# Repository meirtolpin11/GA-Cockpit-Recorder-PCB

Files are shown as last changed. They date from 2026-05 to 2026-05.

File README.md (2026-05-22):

# GA Cockpit Recorder — TRS+TRRS Adapter

Adapter, top view

A small adapter PCB and 3D-printed enclosure for recording audio from a
general aviation (GA) cockpit intercom onto a phone, dictaphone, action
camera, or other consumer recorder.

The board breaks out a GA intercom feed into both **3.5 mm TRS** and
**3.5 mm TRRS** jacks so it can be connected to almost any recording device:

- **TRS** — line-style stereo output (standard recorders, line-in inputs).
- **TRRS** — phone-style 4-conductor output (smartphones, headsets that
  expect a mic on the ring/sleeve).

## Important: this is only the adapter

This board does **not** plug directly into the aircraft. To use it you also
need:

1. **A PL splitter** for the cockpit GA jacks (the dual PJ-055 / PJ-068
   "PL" connectors used in GA aircraft). The splitter taps the intercom
   audio without disconnecting the pilot's headset.
2. **A PL-to-TRS cable or adapter** that connects the splitter to this
   adapter board's input jack.

Signal chain:

```
Cockpit GA jacks ── PL splitter ── PL-to-TRS cable ── [this adapter] ── phone / recorder
```

Example of the PL-to-TRS cable that feeds the adapter:

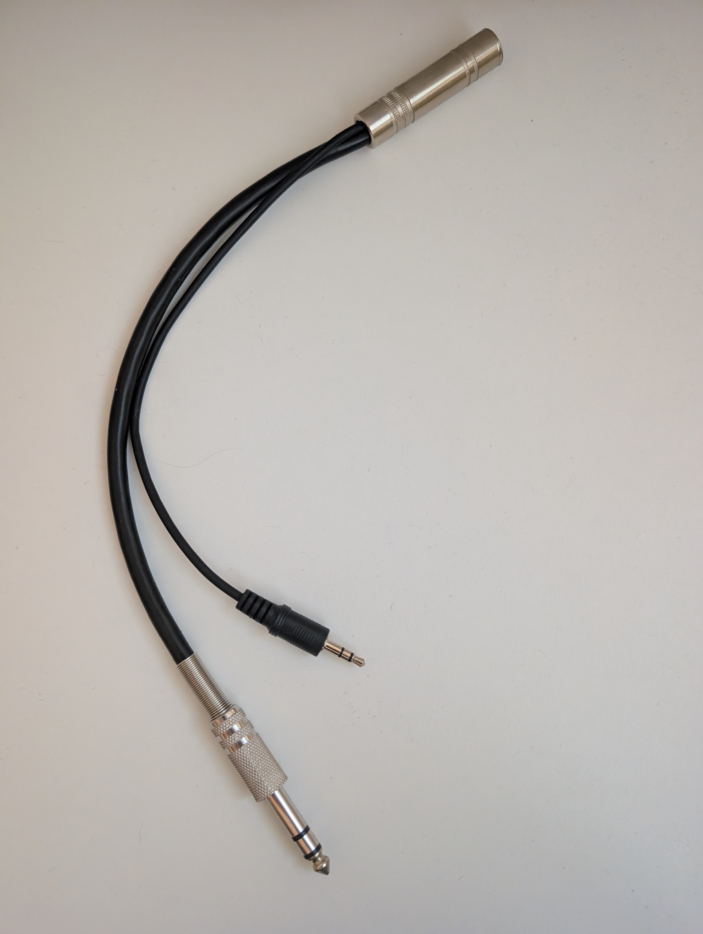
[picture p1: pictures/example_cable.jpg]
Example PL-to-TRS cable


## Connections

| Side | Photo | Description |
|---|---|---|
| Input  | Input | TRS jack — connect the PL-to-TRS cable from the PL splitter here. |
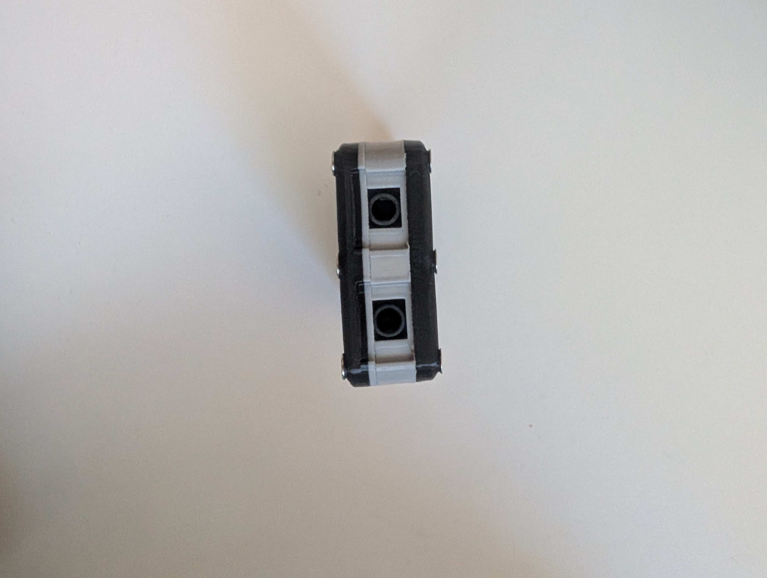
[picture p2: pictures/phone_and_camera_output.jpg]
Output
| Output |  | TRS + TRRS jacks — connect a phone, action camera, or recorder. |

## Schematic

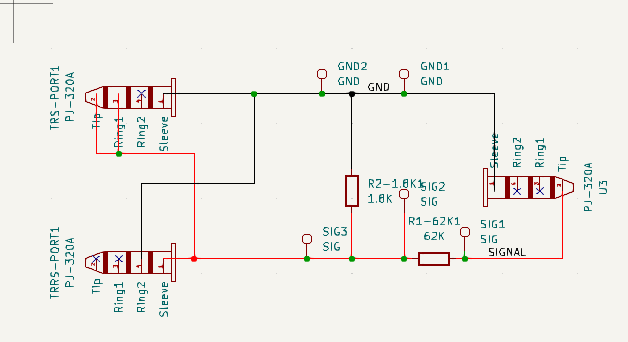
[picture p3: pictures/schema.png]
Schematic


The full editable KiCad schematic is in
[`pcb/Recorder-TRS+TRRS.kicad_sch`](pcb/Recorder-TRS+TRRS.kicad_sch).

## Repository layout

```
pcb/                          KiCad 9 project
  Recorder-TRS+TRRS.kicad_pro     project file
  Recorder-TRS+TRRS.kicad_sch     schematic
  Recorder-TRS+TRRS.kicad_pcb     PCB layout
  PJ-320A.kicad_sym               vendored symbol (upstream ships only legacy .lib)
  PJ-320A_KiCad_Library/          git submodule -> nathanhborger/PJ-320A_KiCad_Library
  sym-lib-table / fp-lib-table    project-local library tables (KIPRJMOD-relative)

case/                         3D-printable enclosure
  top.stl / middle.stl / bottom.stl
  case.3mf                    source file with all parts

pictures/                     photos of the assembled board and case
```

## Opening the KiCad project

The footprint library is a git submodule, so clone with submodules:

```sh
git clone --recurse-submodules git@github.com:meirtolpin11/GA-Cockpit-Recorder-PCB.git
```

If you already cloned without `--recurse-submodules`:

```sh
git submodule update --init
```

Then open `pcb/Recorder-TRS+TRRS.kicad_pro` in KiCad 9.

The project ships its own `sym-lib-table` and `fp-lib-table` using
`${KIPRJMOD}`-relative paths, so no global KiCad library registration is
needed. If you already have a `PJ-320A` / `PJ-320A_Library` entry in your
global tables you may see a duplicate-nickname warning — the project-local
entry is the one that resolves correctly for this project.

## Ordering the PCB

The board has been successfully manufactured by [JLCPCB](https://jlcpcb.com/)
and that is the recommended way to get one made — it's inexpensive, the
turnaround is fast, and the default 1.6 mm FR-4 stack-up works well for
this design.

Gerbers are not committed to the repo (the KiCad design is the source of
truth). To produce manufacturing files yourself:

1. Open `pcb/Recorder-TRS+TRRS.kicad_pcb` in KiCad.
2. **File → Fabrication Outputs → Gerbers** — use the JLCPCB preset or
   the KiCad defaults.
3. **File → Fabrication Outputs → Drill Files** — Excellon, PTH + NPTH.
4. Zip the resulting folder and upload it to
   [jlcpcb.com](https://jlcpcb.com/) (or another fab of your choice).

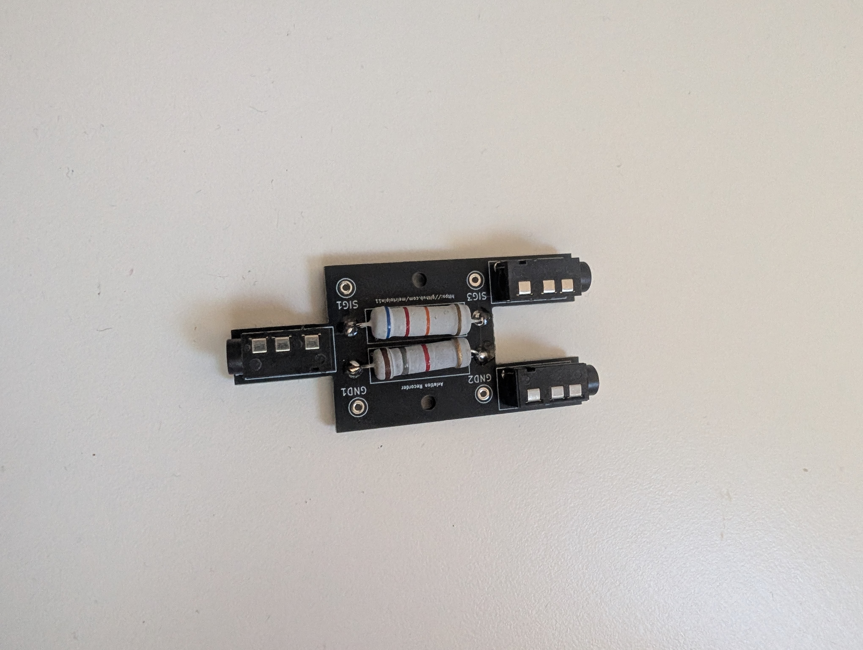
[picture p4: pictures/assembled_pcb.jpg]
Assembled PCB


## Printing the case

The case prints in three parts (`top.stl`, `middle.stl`, `bottom.stl`).
`case.3mf` is the source file containing all parts together — open it in
your slicer if you'd like to print the set in one job.

<p>
  Case, side view
  Case, bottom view
</p>

## Credits

This design is based on the wiring scheme described in this
[Rivet Bangers forum thread](https://www.rivetbangers.com/forums/viewtopic.php?t=4753).

Special thanks to forum user **bullojm1** for sharing the original idea and
schematic — without that write-up this adapter would not exist. Thank you!

## License

This project is licensed under the **Creative Commons
Attribution-NonCommercial-ShareAlike 4.0 International License**
([CC BY-NC-SA 4.0](https://creativecommons.org/licenses/by-nc-sa/4.0/)).

You are free to share and adapt the design for **non-commercial** purposes,
provided you give credit and release your contributions under the same
license. Commercial use is not permitted without prior written permission.
See [`LICENSE`](LICENSE) for the full text.

The PJ-320A library submodule is © its respective authors and used under
the terms of its own repository.

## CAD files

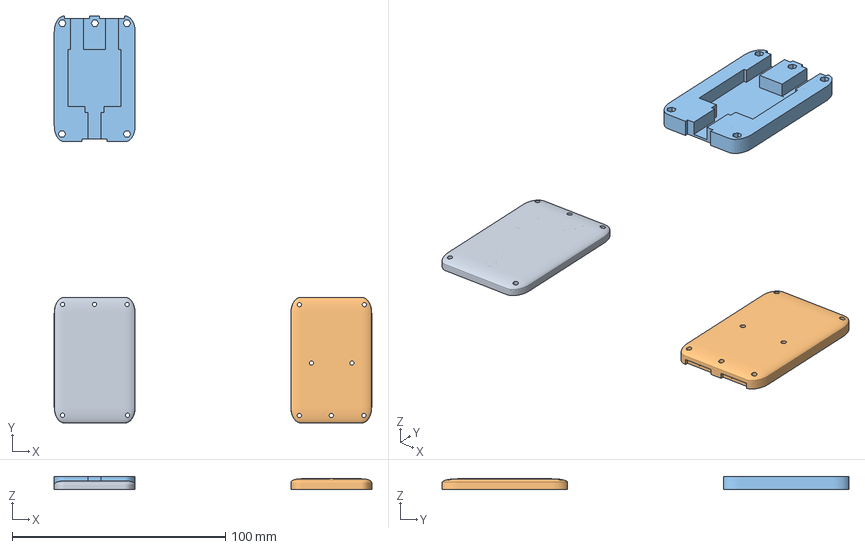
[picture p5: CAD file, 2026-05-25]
case/case.3mf
149.0 x 191.0 x 6.00 mm
Funky Snicket-Uusam (19).stl
Funky Snicket-Uusam (20).stl
Funky Snicket-Uusam (21).stl

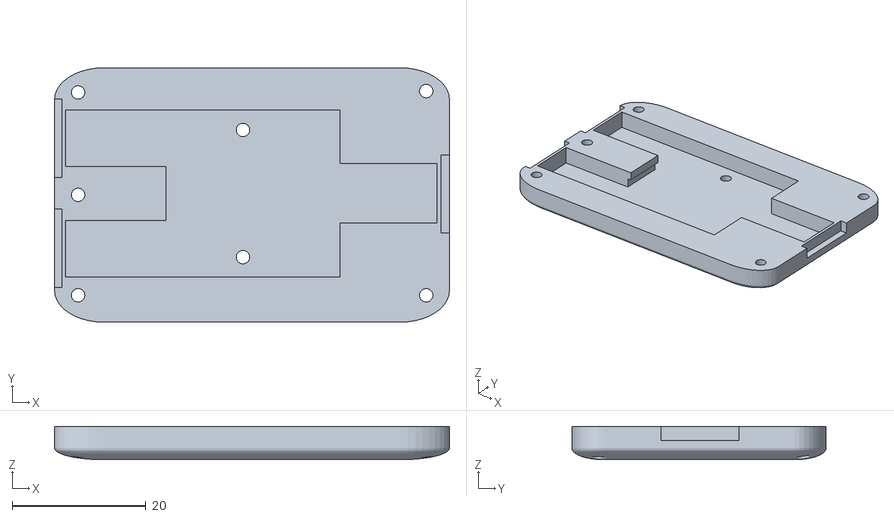
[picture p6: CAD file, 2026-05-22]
case/bottom.stl
59.0 x 38.0 x 4.99

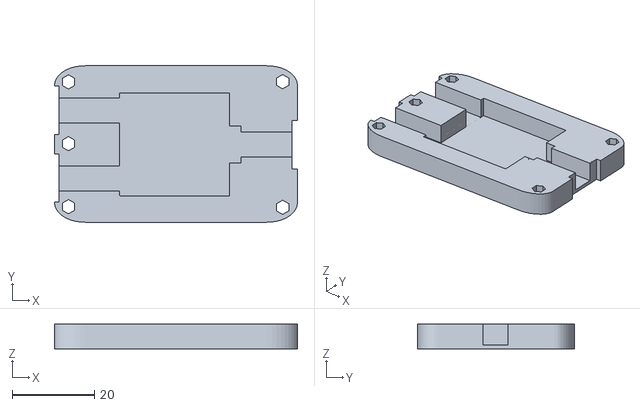
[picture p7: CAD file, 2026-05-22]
case/middle.stl
59.0 x 38.0 x 6.00

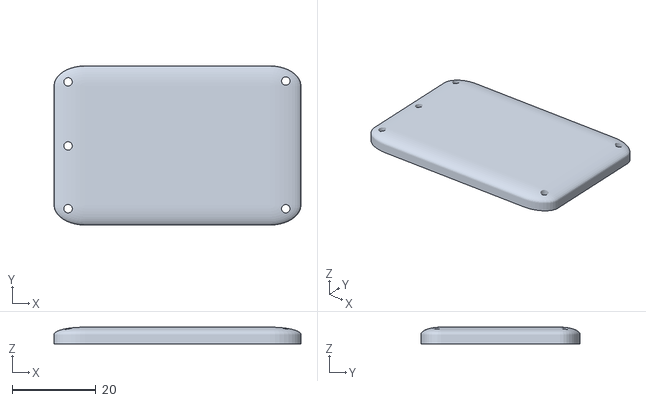
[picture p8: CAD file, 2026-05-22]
case/top.stl
59.0 x 38.0 x 4.00

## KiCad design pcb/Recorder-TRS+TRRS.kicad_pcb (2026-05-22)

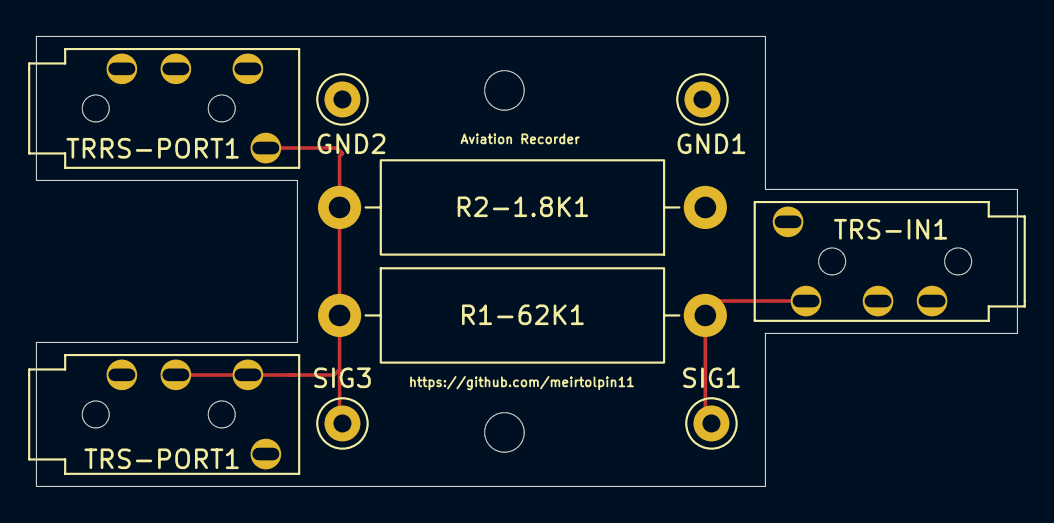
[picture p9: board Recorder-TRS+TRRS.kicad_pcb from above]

Board: 2 copper layers, 54.5 x 25.0 mm, 9 parts (0 on the bottom side), 3 nets.

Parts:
GND1, GND2: GND; TestPoint_Keystone_5000-5004_Miniature
R1-62K1: 62K; R_Axial_DIN0516_L15.5mm_D5.0mm_P20.32mm_Horizontal
R2-1.8K1: 1.8K; R_Axial_DIN0516_L15.5mm_D5.0mm_P20.32mm_Horizontal
SIG1, SIG3: SIG; TestPoint_Keystone_5000-5004_Miniature
TRRS-PORT1: PJ-320A
TRS-IN1: PJ-320A
TRS-PORT1: PJ-320A

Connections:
/GND: GND1.1, GND2.1, R2-1.8K1.1, TRRS-PORT1.4 (Ring2), TRS-IN1.1 (Sleeve), TRS-PORT1.1 (Sleeve)
/SIGNAL: R1-62K1.2, SIG1.1, TRS-IN1.2 (Tip), TRS-IN1.3 (Ring1)
unnamed: R1-62K1.1, R2-1.8K1.2, SIG3.1, TRRS-PORT1.1 (Sleeve), TRS-PORT1.2 (Tip), TRS-PORT1.3 (Ring1)

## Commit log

2026-05-22 Initial commit: Recorder-TRS+TRRS KiCad project
    PCB design source for the TRS+TRRS Recorder board.
    PJ-320A footprint sourced from upstream as a submodule;
    symbol vendored since upstream only ships legacy .lib format.
    [Recorder-TRS+TRRS.kicad_pcb, Recorder-TRS+TRRS.kicad_sch]
2026-05-22 Add case/ folder for enclosure 3D files
    Scope manufacturing-output ignore rules to pcb/ so future case files
    (STEP/STL/etc.) are tracked rather than silently ignored.
2026-05-22 Add enclosure case files (top/middle/bottom STL + 3MF source)
    [bottom.stl, case.3mf, middle.stl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]
2026-05-22 Add README and project photos
    README documents the adapter purpose, required external parts (PL splitter
    and PL-to-TRS cable), KiCad workflow, and case printing. Credits the
    original wiring scheme from a Rivet Bangers forum thread by user bullojm1.
2026-05-22 Add schematic image to README
2026-05-22 Recommend JLCPCB for PCB manufacturing
2026-05-25 Updated case setting
    [case.3mf]
